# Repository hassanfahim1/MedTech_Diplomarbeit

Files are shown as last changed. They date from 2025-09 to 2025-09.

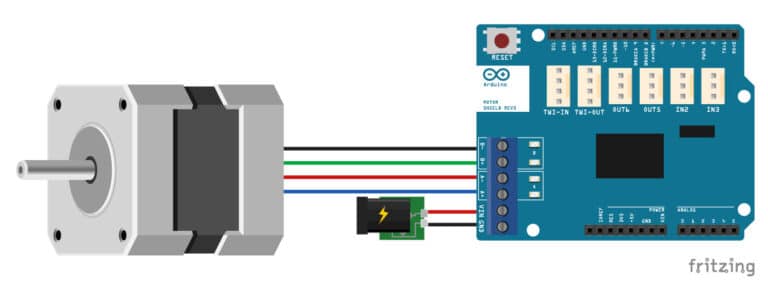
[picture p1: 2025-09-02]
images/Arduino-Motor-Shield-Rev3-with-Stepper-Motor-Wiring-Diagram-Schematic-Pinout-Fritzing-768x290.jpg

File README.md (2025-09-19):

# MedTech_Diplomarbeit | Open Source Spritzenpumpe

Eine präzise, temperaturoptimierte Spritzenpumpe für medizinische und Laboranwendungen.

## 🎯 Features

- **Präzise Volumensteuerung** für 5ml und 10ml Spritzen
- **Temperaturoptimiert** - Motor wird nicht warm durch intelligente Steuerung
- **Einfache Bedienung** mit nur 3 Buttons
- **LCD-Display** mit deutscher Benutzeroberfläche
- **Not-Halt Funktion** für sicheren Betrieb
- **Open Source** - alle Dateien frei verfügbar

## 🔧 Hardware

### Benötigte Komponenten:
- Arduino Leonardo
- Motor Shield Rev3 (L298P)
- NEMA17 Schrittmotor (17HS08-1004S, 3V/1A)
- I2C LCD Display (16x2)
- 3x Taster (Start/Stop, Füllen, Entleeren)
- 5ml oder 10ml Spritzen

### Anschlüsse:
- **Start/Stop Button:** Pin 2
- **Füllen Button:** Pin 7  
- **Entleeren Button:** Pin 5
- **LCD:** I2C (SDA/SCL)
- **Motor Shield:** Standard Pins (3, 8, 9, 11, 12, 13)

## 💾 Code

### Verfügbare Versionen:
- **`spritzenpumpe_5ml.ino`** - Optimiert für 5ml Spritzen
- **`spritzenpumpe_10ml.ino`** - Optimiert für 10ml Spritzen
- **`Spritzenpumpe_10ml_5ml_RotaryEncoder.ino`** - Universalversion mit Rotary Encoder (5ml + 10ml wählbar)

### Installation:
1. Arduino IDE installieren
2. Benötigte Libraries installieren:
   ```
   - Wire.h (Standard)
   - LiquidCrystal_I2C.h
   - Stepper.h (Standard)
   ```
3. Gewünschte Version auf Arduino Leonardo hochladen

## 🚀 Bedienung

1. **Einschalten** - Display zeigt "Ready..."
2. **Füllen** - Button "Füllen" drücken
3. **Entleeren** - Button "Entleeren" drücken  
4. **Start/Stop** - Jederzeit Motor stoppen/starten

### Display-Anzeigen:
- Aktuelles Volumen in ml
- Füll-/Entleervorgang mit Fortschrittsbalken
- Status: "BEREIT" oder "LAUFEND"

## ⚡ Temperatur-Optimierung

**Problem gelöst:** Motor wird nicht mehr warm!

### Technische Lösung:
- Motor nur bei Bewegung bestromt
- Automatische Freigabe nach 2s Inaktivität
- `motorEnable()` / `motorRelease()` Funktionen
- Bis zu 90% weniger Wärmeentwicklung

## 📋 Technische Daten

### 5ml Version:
- Schritte pro ml: 850
- Schritte pro Bewegung: 4250
- Maximales Volumen: 5.00ml

### 10ml Version:  
- Schritte pro ml: 590
- Schritte pro Bewegung: 5900
- Maximales Volumen: 10.00ml

## ⚠️ Wichtige Hinweise

- **L298P hat keine Stromregelung** - Temperatur-Feature ist essentiell
- **Nur für Laboranwendungen** - nicht für medizinische Direktanwendung
- **Kalibrierung** je nach Spritze eventuell anpassen
- **Sicherheit** - immer Not-Halt griffbereit

## 📁 Projektstruktur

```
MedTech_Diplomarbeit/
├── CAD/                        # CAD-Dateien und Zeichnungen
├── Schema/                     # Schaltpläne und Schemas
├── images/                     # Bilder und Dokumentation
├── scr/                        # Source Code
│   ├── spritzenpumpe_5ml.ino                      # Code für 5ml Spritzen
│   ├── spritzenpumpe_10ml.ino                     # Code für 10ml Spritzen
│   └── Spritzenpumpe_10ml_5ml_RotaryEncoder.ino   # Universalversion mit Encoder
└── README.md                   # Diese Datei
```

## 🛠️ Entwicklung

**Hauptverbesserungen in V1.2:**
- ✅ Temperaturproblem gelöst
- ✅ Encoder entfernt für Einfachheit
- ✅ Separate Versionen für 5ml/10ml
- ✅ Verbesserte Benutzeroberfläche

## 📜 Lizenz

Open Source - frei für Bildung und Forschung verwendbar.

## 🔗 Repository

**GitHub:** https://github.com/hassanfahim1/MedTech_Diplomarbeit

---

*Entwickelt als Teil einer Diplomarbeit im Bereich Medizintechnik*

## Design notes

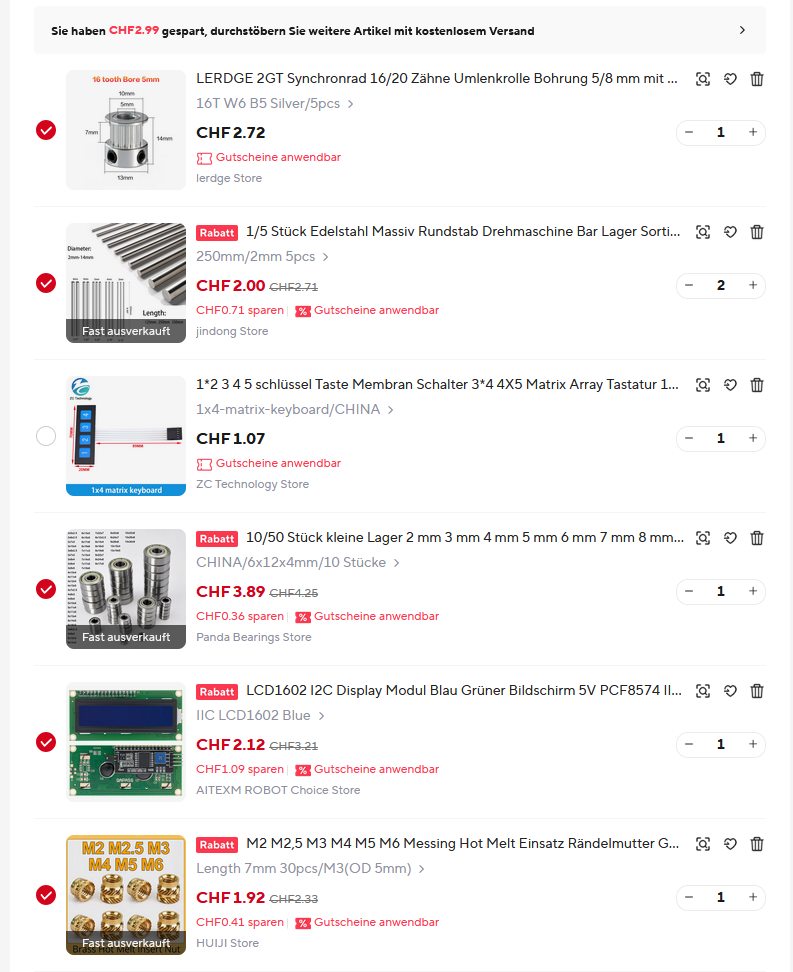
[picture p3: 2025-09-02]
images/Screenshot 2025-08-20 134111.png

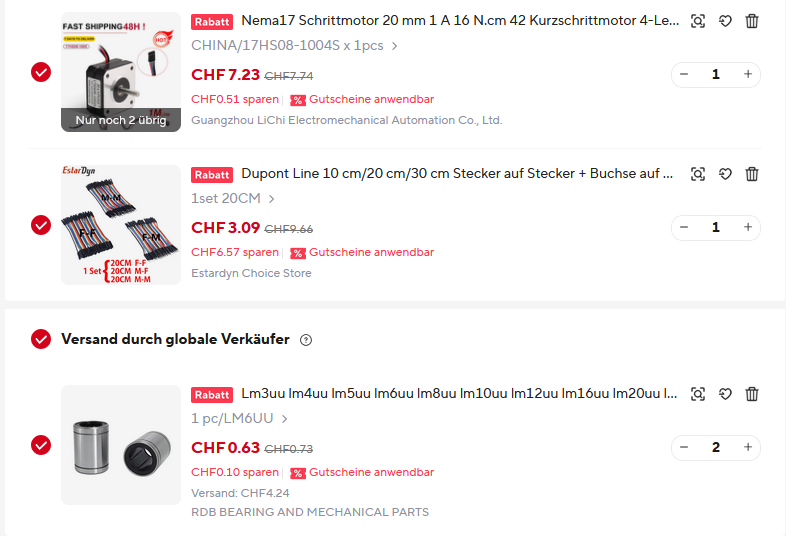
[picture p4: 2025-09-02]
images/Screenshot 2025-08-20 134125.png

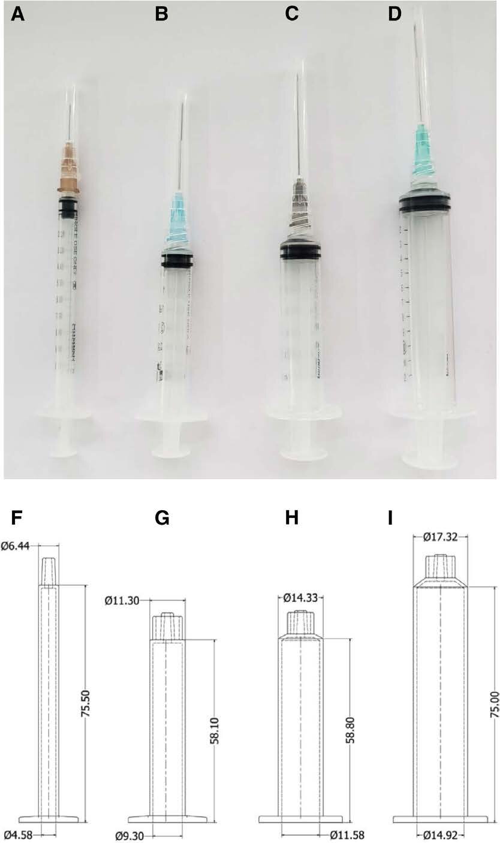
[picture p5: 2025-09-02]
images/Syringe-A-1-mL-B-3-mL-C-5-mL-D-10-mL-and-the-dimension-detail-of-the-barrel.jpg

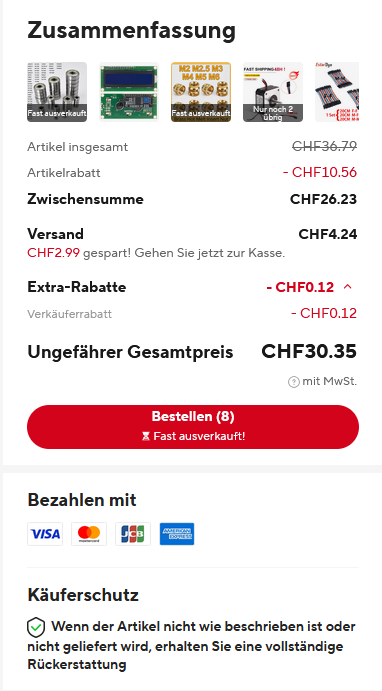
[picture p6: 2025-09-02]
images/Screenshot 2025-08-20 134036.png

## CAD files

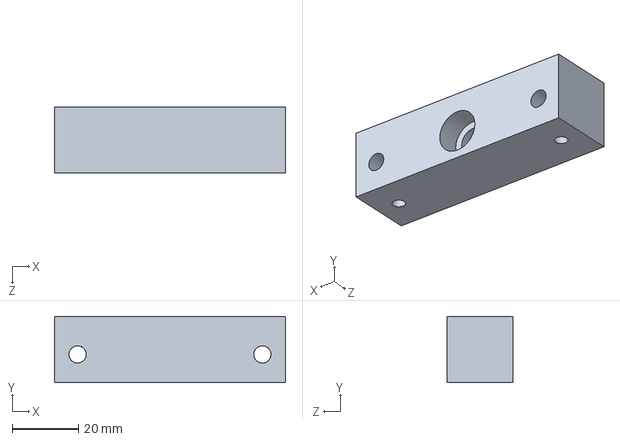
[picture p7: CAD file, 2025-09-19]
CAD/SLDPRT Bauteile/EndTeil ohne Gehäuse.SLDPRT
70.0 x 20.0 x 20.0 mm

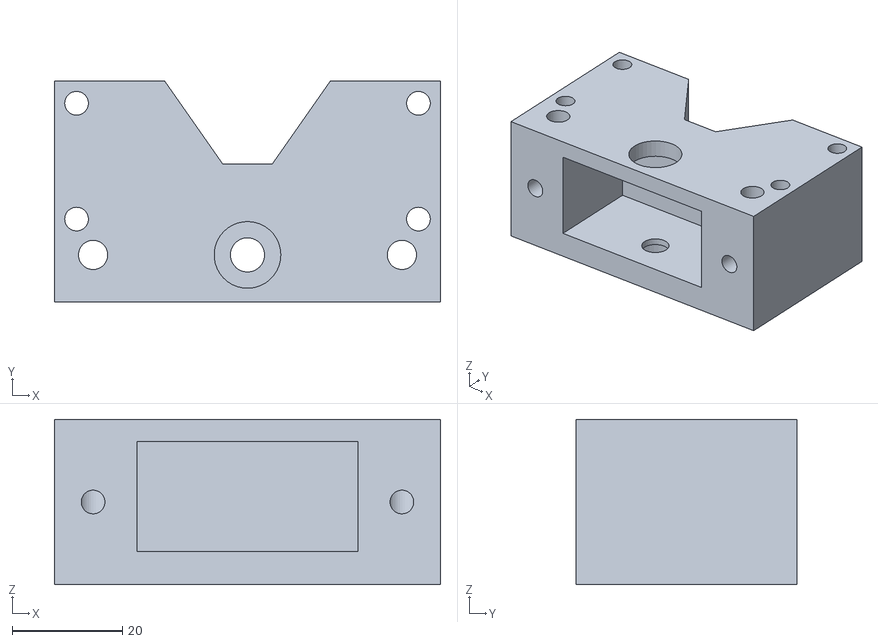
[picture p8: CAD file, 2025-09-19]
CAD/STL Datein/Motorenteil_Spritzenhalter.STL
70.0 x 40.0 x 30.0

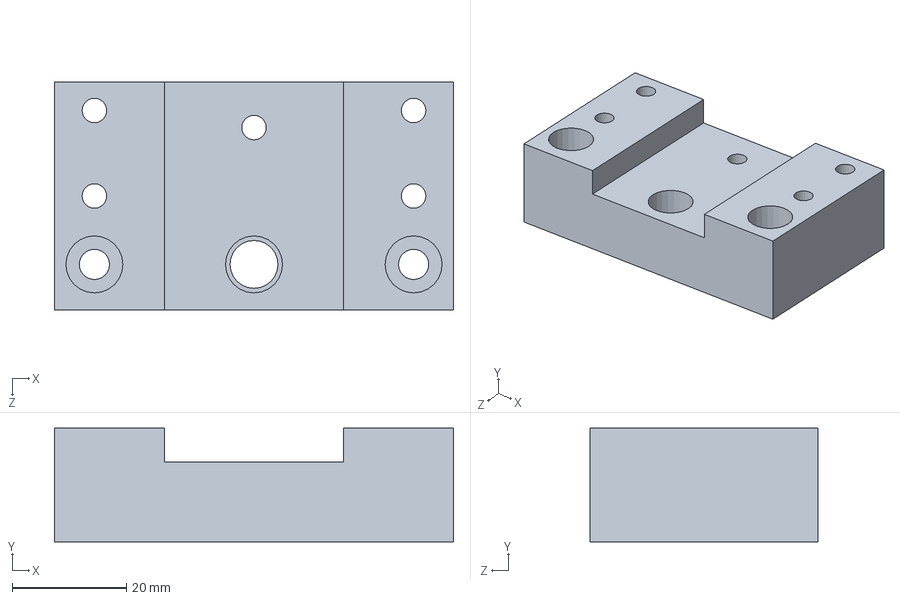
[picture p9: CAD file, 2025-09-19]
CAD/SLDPRT Bauteile/Mittlerer_Teil_Spritzenschieber.SLDPRT
70.0 x 20.0 x 40.0 mm

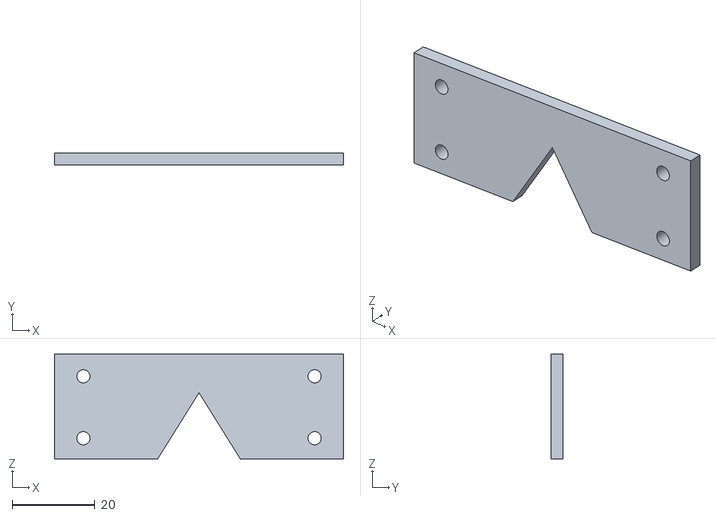
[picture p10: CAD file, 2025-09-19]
CAD/STL Datein/SchiebeTeilSpritzenhalter.STL
70.0 x 3.00 x 25.4

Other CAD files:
CAD/SLDPRT Bauteile/SchiebeTeil.SLDPRT
CAD/STL Datein/Mittlerer_Teil_Spritzenschieber.STL
CAD/SLDPRT Bauteile/Motorenteil_Spritzenhalter.SLDPRT
CAD/STL Datein/EndTeil.STL
CAD/Zeichnungen/EndTeil.SLDDRW
CAD/Zeichnungen/Mittlerer_Teil_Spritzenschieber.SLDDRW
CAD/Zeichnungen/Motorenteil_Spritzenhalter.SLDDRW
CAD/Zeichnungen/SchiebeTeil_Spritzenhalter.SLDDRW

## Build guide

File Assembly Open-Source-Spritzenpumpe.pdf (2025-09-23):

# Assembly Open-Source-Spritzenpumpe

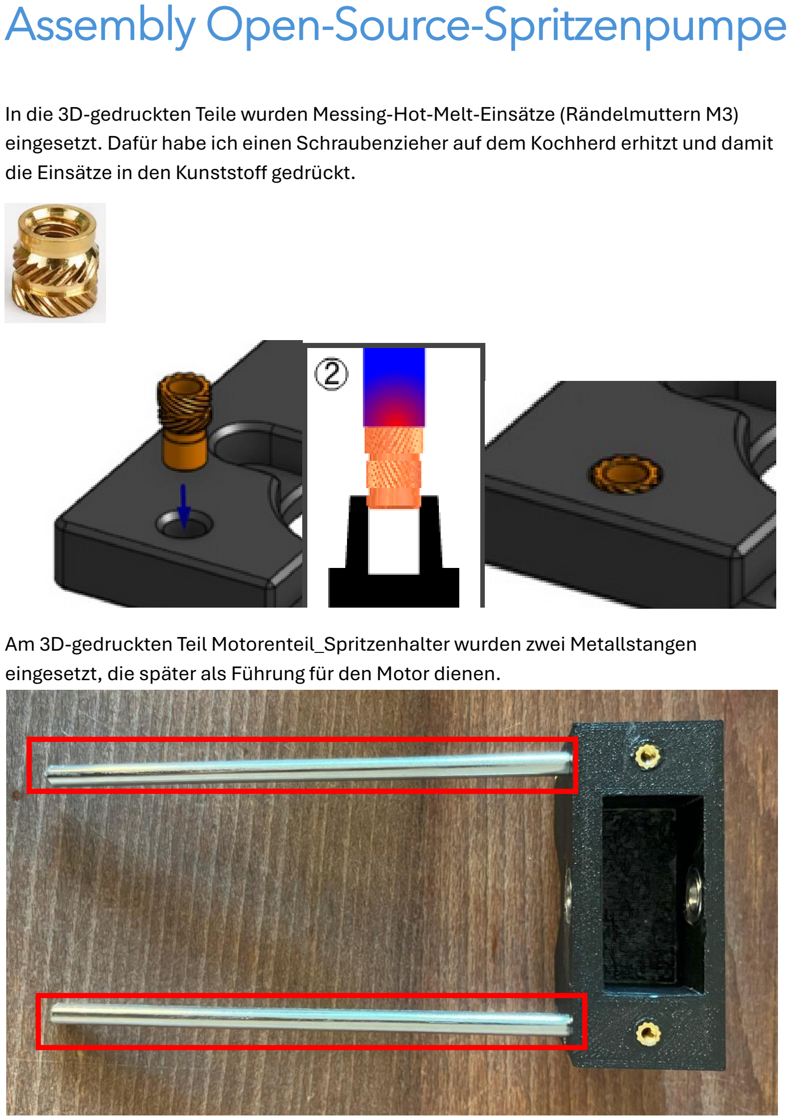
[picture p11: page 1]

In die 3D-gedruckten Teile wurden Messing-Hot-Melt-Einsätze (Rändelmuttern M3) eingesetzt. Dafür habe ich einen Schraubenzieher auf dem Kochherd erhitzt und damit die Einsätze in den Kunststoff gedrückt.

Am 3D-gedruckten Teil Motorenteil_Spritzenhalter wurden zwei Metallstangen eingesetzt, die später als Führung für den Motor dienen.

In der Mitte des Teils Motorenteil_Spritzenhalter wurde die Gewindestange eingesetzt. Darauf wurde ein LERDGE 2GT-Synchronrad mit einem GT2-Zahnriemen (106 mm, Gummi) montiert.

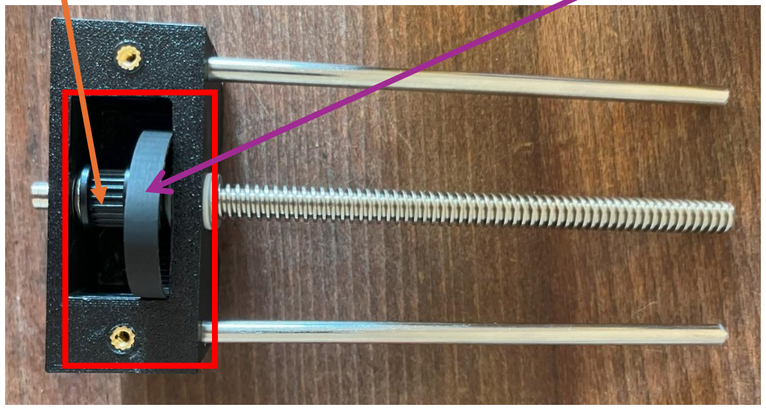
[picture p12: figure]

Im mittleren 3D-Teil der Spritze wurde eine T8-Leitspindel mit Mutter eingesetzt. An den beiden unteren Seiten dieses Teils wurden zwei lineare Kugellager (LM5UU) eingebaut. Dadurch kann sich der Kolben (Mittlerer_Teil_Spritzenschieber) leicht und stabil bewegen.

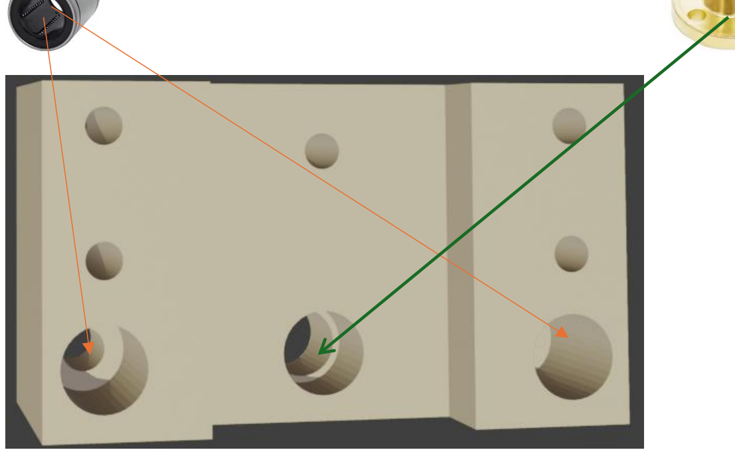
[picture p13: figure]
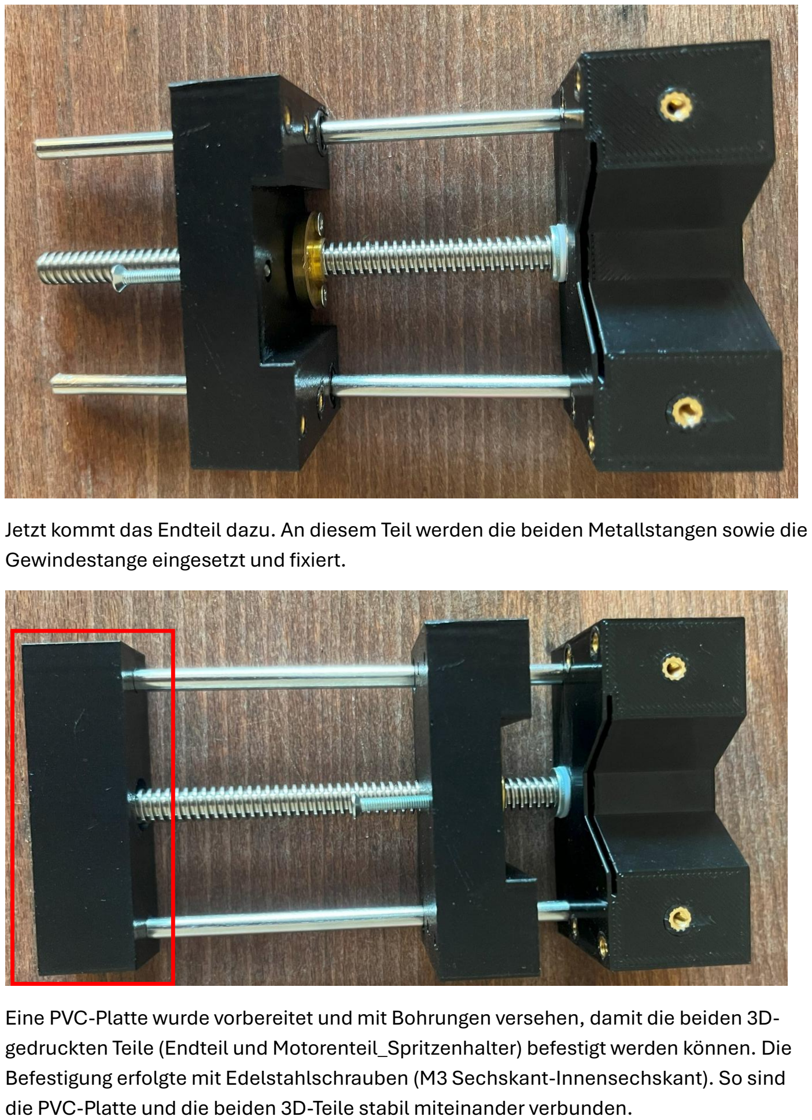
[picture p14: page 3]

Jetzt kommt das Endteil dazu. An diesem Teil werden die beiden Metallstangen sowie die Gewindestange eingesetzt und fixiert.

Eine PVC-Platte wurde vorbereitet und mit Bohrungen versehen, damit die beiden 3D-gedruckten Teile (Endteil und Motorenteil_Spritzenhalter) befestigt werden können. Die Befestigung erfolgte mit Edelstahlschrauben (M3 Sechskant-Innensechskant). So sind die PVC-Platte und die beiden 3D-Teile stabil miteinander verbunden.

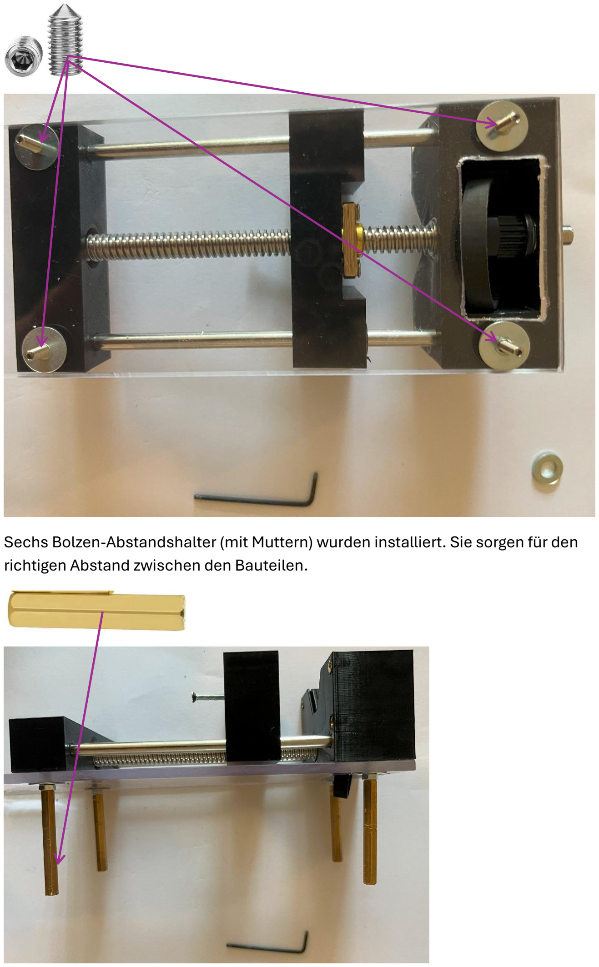
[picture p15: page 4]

Sechs Bolzen-Abstandshalter (mit Muttern) wurden installiert. Sie sorgen für den richtigen Abstand zwischen den Bauteilen.

Eine zweite PVC-Platte wurde vorbereitet, die von unten montiert wird. Damit ist die Spritze vollständig eingefasst. Beide PVC-Platten bilden zusammen ein Gehäuse, in dem sich alle Elektronikteile sowie der Motor befinden.

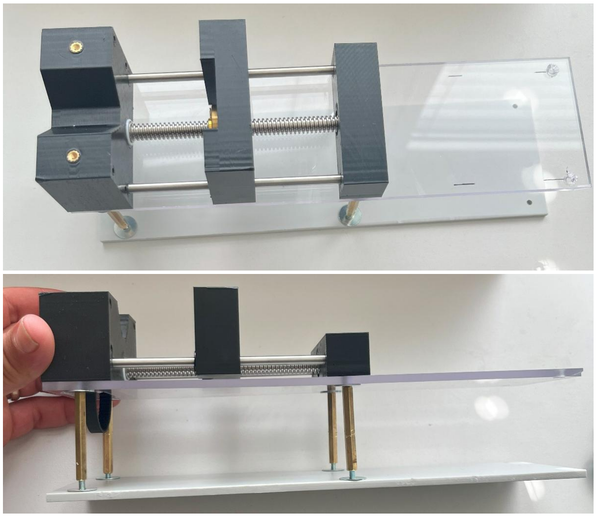
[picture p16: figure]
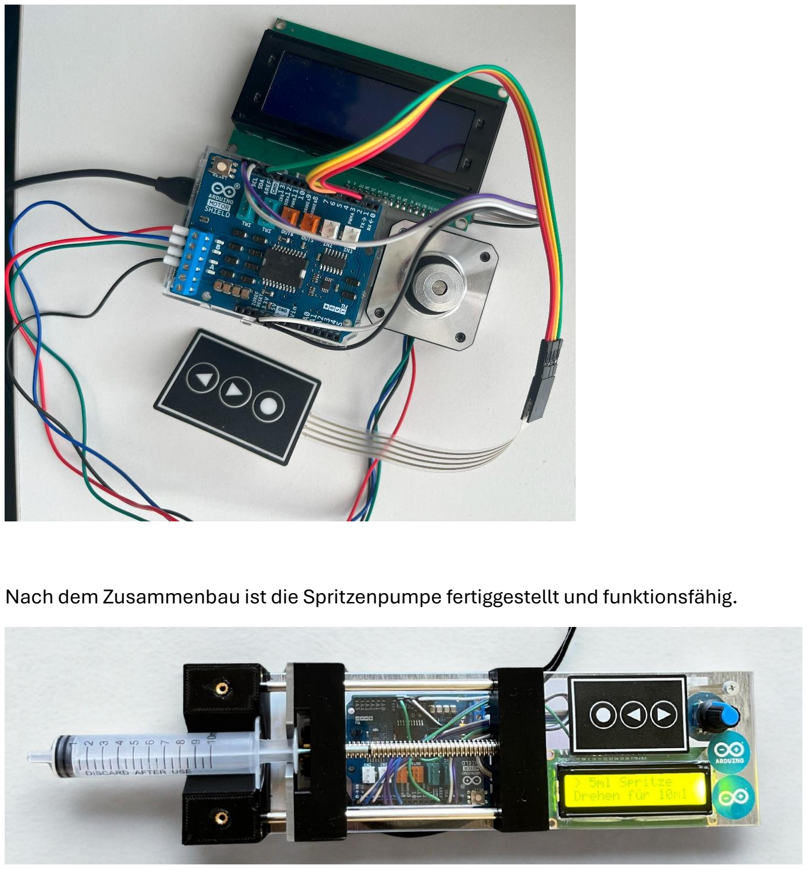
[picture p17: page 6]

Nach dem Zusammenbau ist die Spritzenpumpe fertiggestellt und funktionsfähig.

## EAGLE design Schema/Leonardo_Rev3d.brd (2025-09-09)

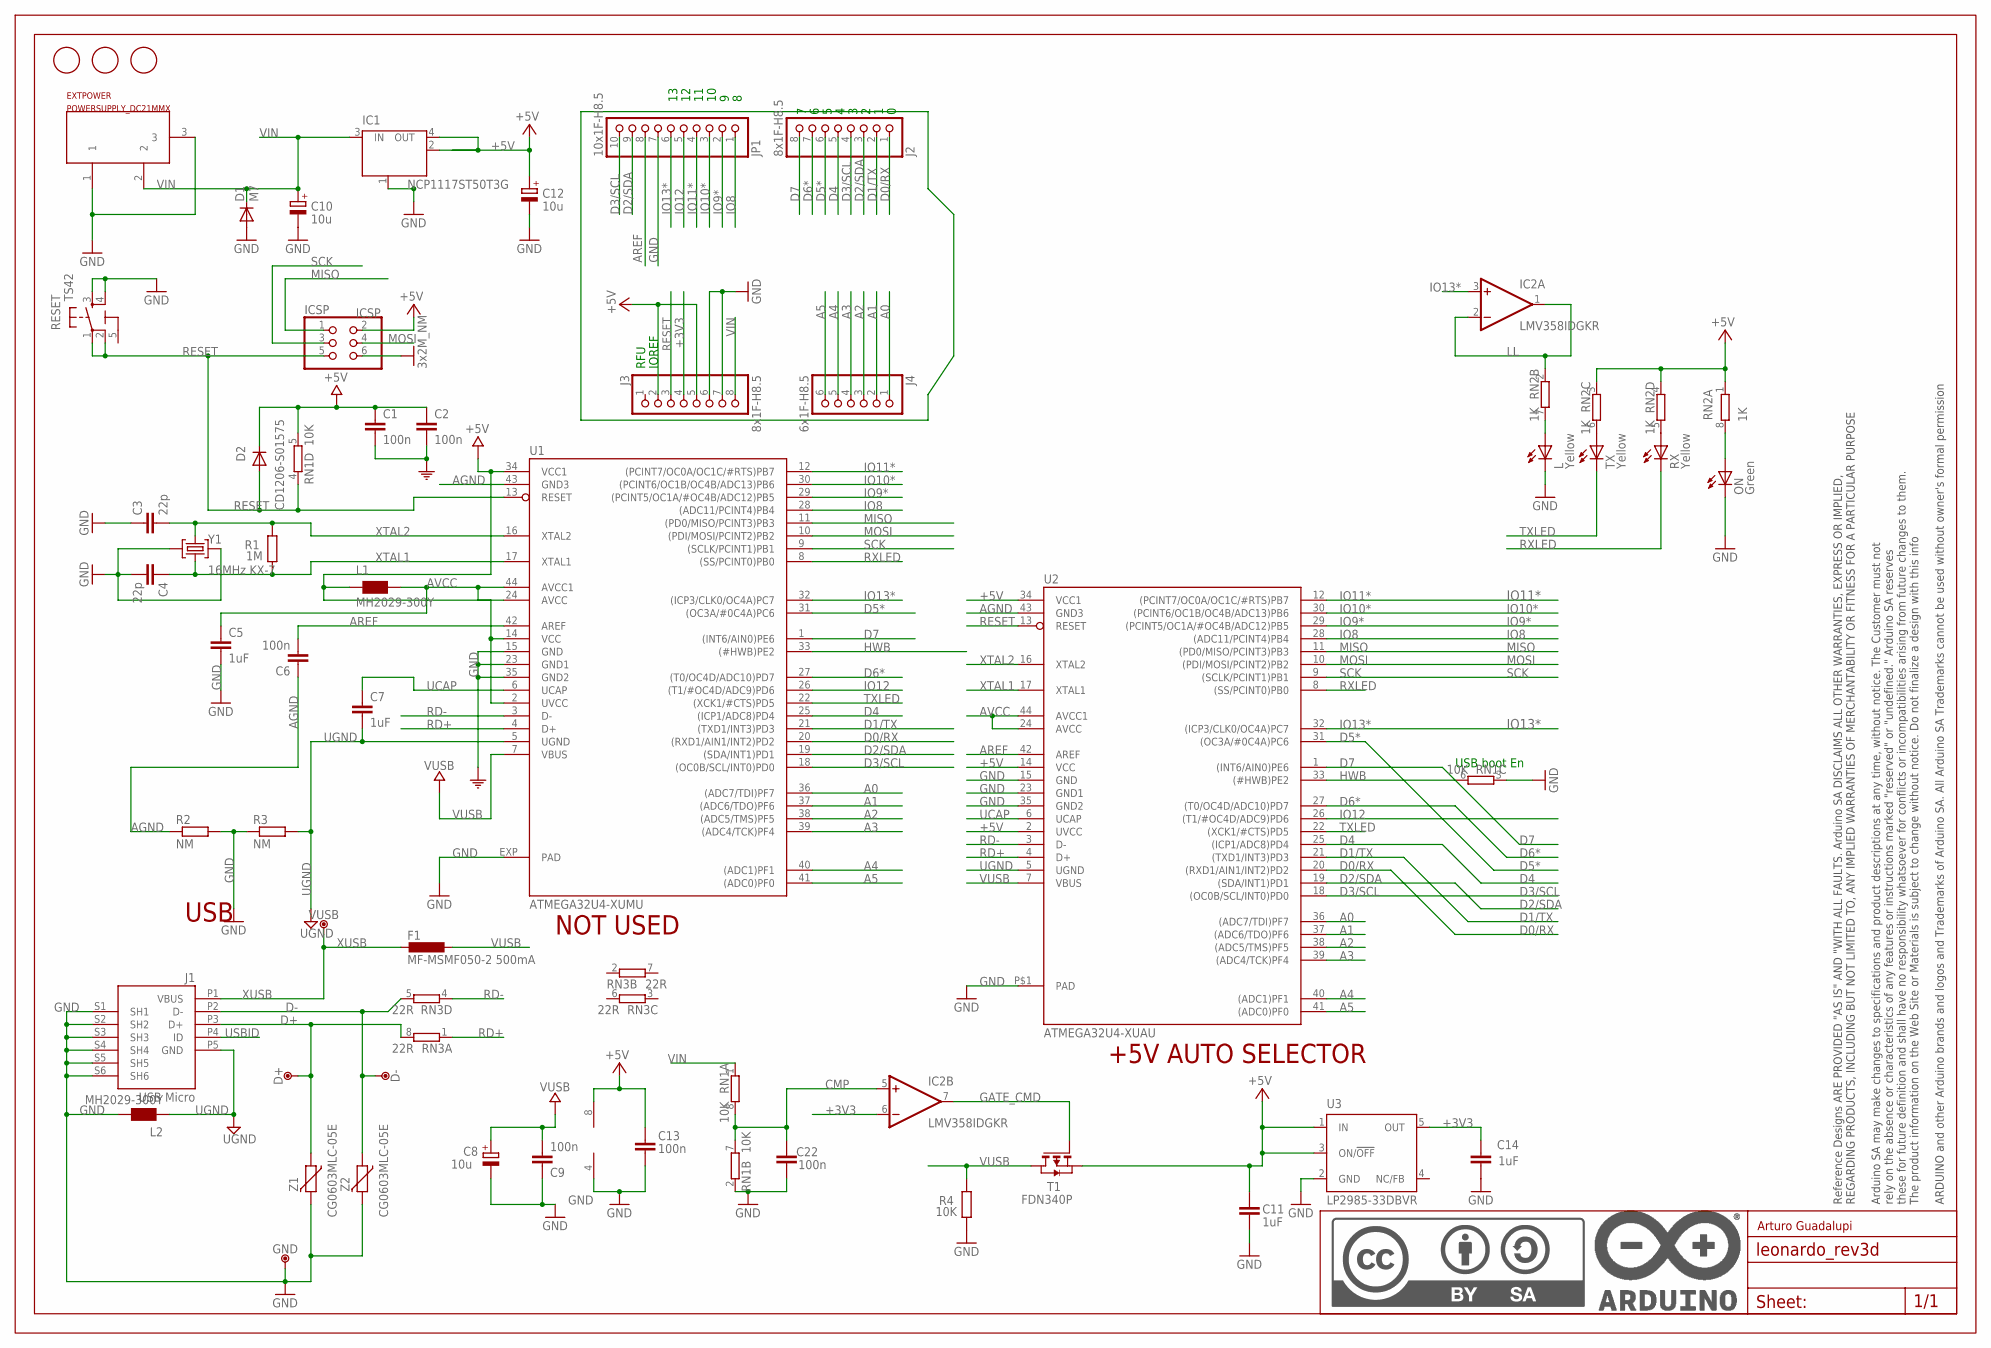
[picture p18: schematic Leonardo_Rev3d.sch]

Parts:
C1, C2, C6, C9, C13, C22: 100n; C0603-ROUND
C3, C4: 22p; C0603-ROUND
C5, C7, C11, C14: 1uF; C0603-ROUND
C8, C10, C12: 10u; SMC_B
D1: M7; SMB
D2: CD1206-S01575; MINIMELF
D+: DNP; TP-1.00MM
D-: DNP; TP-1.00MM
EXTPOWER: POWERSUPPLY_DC21MMX; POWERSUPPLY_DC-21MM
F1: MF-MSMF050-2 500mA; L1812
FID1, FID2, FID3: DNP; FD-1-1.5
FRAME1: DNP; FRAME
GND: DNP; TP-1.00MM
IC1: NCP1117ST50T3G; SOT223
IC2: LMV358IDGKR; MSOP08
ICSP: ICSP; 2X03
J1: USB Micro; CON2_USB_MICRO_B_AT
J2, J3: 8x1F-H8.5; 1X08
J4: 6x1F-H8.5; 1X06
JP1: 10x1F-H8.5; 1X10
L: Yellow; CHIPLED_0805
L1, L2: MH2029-300Y; 0805
ON: Green; CHIPLED_0805
R1: 1M; R0603-ROUND
R2, R3: NM; R0402
R4: 10K; R0603-ROUND
RESET: TS42
RN1: 10K; CAY16
RN2: 1K; CAY16
RN3: 22R; CAY16
RX: Yellow; CHIPLED_0805
T1: FDN340P; SOT-23
TX: Yellow; CHIPLED_0805
U1: ATMEGA32U4-XUMU; QFN44ML7X7
U2: ATMEGA32U4-XUAU; TQFP44-PAD
U3: LP2985-33DBVR; SOT23-DBV
VUSB: DNP; TP-1.00MM
Y1: 16MHz KX-7; CRYSTAL-3.2-2.5
Z1, Z2: CG0603MLC-05E; CT/CN0603

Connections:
5-GND: RESET.5 (5-GND)
+3V3: C14.2, IC2.6 (-IN), J3.4, U3.5 (OUT)
+5V: C1.1, C2.1, C11.2, C12.+, C13.1, D2.C, IC1.2 (OUT), IC1.4 (OUT), IC2.8 (V+), ICSP.2, J3.2, J3.5, L1.1, RN1.5 (2), RN2.1, RN2.3 (1), RN2.4 (1), T1.2 (S), U1.2 (UVCC), U1.14 (VCC), U1.34 (VCC1), U2.2 (UVCC), U2.14 (VCC), U2.34 (VCC1), U3.1 (IN), U3.3 (ON/!OFF)
A0: J4.1, U1.36 ((ADC7/TDI)PF7), U2.36 ((ADC7/TDI)PF7)
A1: J4.2, U1.37 ((ADC6/TDO)PF6), U2.37 ((ADC6/TDO)PF6)
A2: J4.3, U1.38 ((ADC5/TMS)PF5), U2.38 ((ADC5/TMS)PF5)
A3: J4.4, U1.39 ((ADC4/TCK)PF4), U2.39 ((ADC4/TCK)PF4)
A4: J4.5, U1.40 ((ADC1)PF1), U2.40 ((ADC1)PF1)
A5: J4.6, U1.41 ((ADC0)PF0), U2.41 ((ADC0)PF0)
AGND: C6.1, R2.1, U1.43 (GND3), U2.43 (GND3)
AREF: C6.2, JP1.8, U1.42 (AREF), U2.42 (AREF)
AVCC: C5.1, L1.2, U1.24 (AVCC), U1.44 (AVCC1), U2.24 (AVCC), U2.44 (AVCC1)
CMP: C22.2, IC2.5 (+IN), RN1.7 (2), RN1.8 (2)
D0/RX: J2.1, U1.20 ((RXD1/AIN1/INT2)PD2), U2.20 ((RXD1/AIN1/INT2)PD2)
D1/TX: J2.2, U1.21 ((TXD1/INT3)PD3), U2.21 ((TXD1/INT3)PD3)
D2/SDA: J2.3, JP1.9, U1.19 ((SDA/INT1)PD1), U2.19 ((SDA/INT1)PD1)
D3/SCL: J2.4, JP1.10, U1.18 ((OC0B/SCL/INT0)PD0), U2.18 ((OC0B/SCL/INT0)PD0)
D4: J2.5, U1.25 ((ICP1/ADC8)PD4), U2.25 ((ICP1/ADC8)PD4)
D5*: J2.6, U1.31 ((OC3A/#0C4A)PC6), U2.31 ((OC3A/#0C4A)PC6)
D6*: J2.7, U1.27 ((T0/OC4D/ADC10)PD7), U2.27 ((T0/OC4D/ADC10)PD7)
D7: J2.8, U1.1 ((INT6/AIN0)PE6), U2.1 ((INT6/AIN0)PE6)
D+: D+.X, J1.P3 (D+), RN3.8 (2), Z1.1
D-: D-.X, J1.P2 (D-), RN3.5 (2), Z2.1
GATE_CMD: IC2.7 (OUT), T1.3 (G)
GND: C1.2, C2.2, C3.1, C4.2, C5.2, C8.-, C9.1, C10.-, C11.1, C12.-, C13.2, C14.1, C22.1, D1.A, EXTPOWER.1, EXTPOWER.3, GND.X, IC1.1 (GND/ADJ), IC2.4 (V-), ICSP.6, J1.S1 (SH1), J1.S2 (SH2), J1.S3 (SH3), J1.S4 (SH4), J1.S5 (SH5), J1.S6 (SH6), J3.6, J3.7, JP1.7, L.C, L2.2, ON.C, R2.2, R3.1, R4.1, RESET.3, RESET.4, RN1.2 (1), RN1.3 (1), U1.15 (GND), U1.23 (GND1), U1.35 (GND2), U1.EXP (PAD), U2.15 (GND), U2.23 (GND1), U2.35 (GND2), U2.P$1 (PAD), U3.2 (GND), Y1.2 (GND), Y1.4 (GND), Z1.2, Z2.2
HWB: RN1.6 (2), U1.33 ((#HWB)PE2), U2.33 ((#HWB)PE2)
IO8: JP1.1, U1.28 ((ADC11/PCINT4)PB4), U2.28 ((ADC11/PCINT4)PB4)
IO9*: JP1.2, U1.29 ((PCINT5/OC1A/#OC4B/ADC12)PB5), U2.29 ((PCINT5/OC1A/#OC4B/ADC12)PB5)
IO10*: JP1.3, U1.30 ((PCINT6/OC1B/OC4B/ADC13)PB6), U2.30 ((PCINT6/OC1B/OC4B/ADC13)PB6)
IO11*: JP1.4, U1.12 ((PCINT7/OC0A/OC1C/#RTS)PB7), U2.12 ((PCINT7/OC0A/OC1C/#RTS)PB7)
IO12: JP1.5, U1.26 ((T1/#OC4D/ADC9)PD6), U2.26 ((T1/#OC4D/ADC9)PD6)
IO13*: IC2.3 (+IN), JP1.6, U1.32 ((ICP3/CLK0/OC4A)PC7), U2.32 ((ICP3/CLK0/OC4A)PC7)
LL: IC2.1 (OUT), IC2.2 (-IN), RN2.2 (1)
MISO: ICSP.1, U1.11 ((PD0/MISO/PCINT3)PB3), U2.11 ((PD0/MISO/PCINT3)PB3)
MOSI: ICSP.4, U1.10 ((PDI/MOSI/PCINT2)PB2), U2.10 ((PDI/MOSI/PCINT2)PB2)
unnamed: L.A, RN2.7 (2)
unnamed: ON.A, RN2.8 (2)
unnamed: RN2.6 (2), TX.A
unnamed: RN2.5 (2), RX.A
RD+: RN3.1, U1.4 (D+), U2.4 (D+)
RD-: RN3.4 (1), U1.3 (D-), U2.3 (D-)
RESET: D2.A, ICSP.5, J3.3, RESET.1, RESET.2, RN1.4 (1), U1.13 (RESET), U2.13 (RESET)
RXLED: RX.C, U1.8 ((SS/PCINT0)PB0), U2.8 ((SS/PCINT0)PB0)
SCK: ICSP.3, U1.9 ((SCLK/PCINT1)PB1), U2.9 ((SCLK/PCINT1)PB1)
TXLED: TX.C, U1.22 ((XCK1/#CTS)PD5), U2.22 ((XCK1/#CTS)PD5)
UCAP: C7.1, U1.6 (UCAP), U2.6 (UCAP)
UGND: C7.2, J1.P5 (GND), L2.1, R3.2, U1.5 (UGND), U2.5 (UGND)
USBID: J1.P4 (ID)
VIN: C10.+, D1.C, EXTPOWER.2, IC1.3 (IN), J3.8, RN1.1
VUSB: C8.+, C9.2, F1.1, R4.2, T1.1 (D), U1.7 (VBUS), U2.7 (VBUS)
XTAL1: C4.1, R1.1, U1.17 (XTAL1), U2.17 (XTAL1), Y1.1 (C1)
XTAL2: C3.2, R1.2, U1.16 (XTAL2), U2.16 (XTAL2), Y1.3 (C2)
XUSB: F1.2, J1.P1 (VBUS), VUSB.X

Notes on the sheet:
USB boot En
USB
+5V AUTO SELECTOR
NOT USED
IOREF
RFU
Arturo Guadalupi

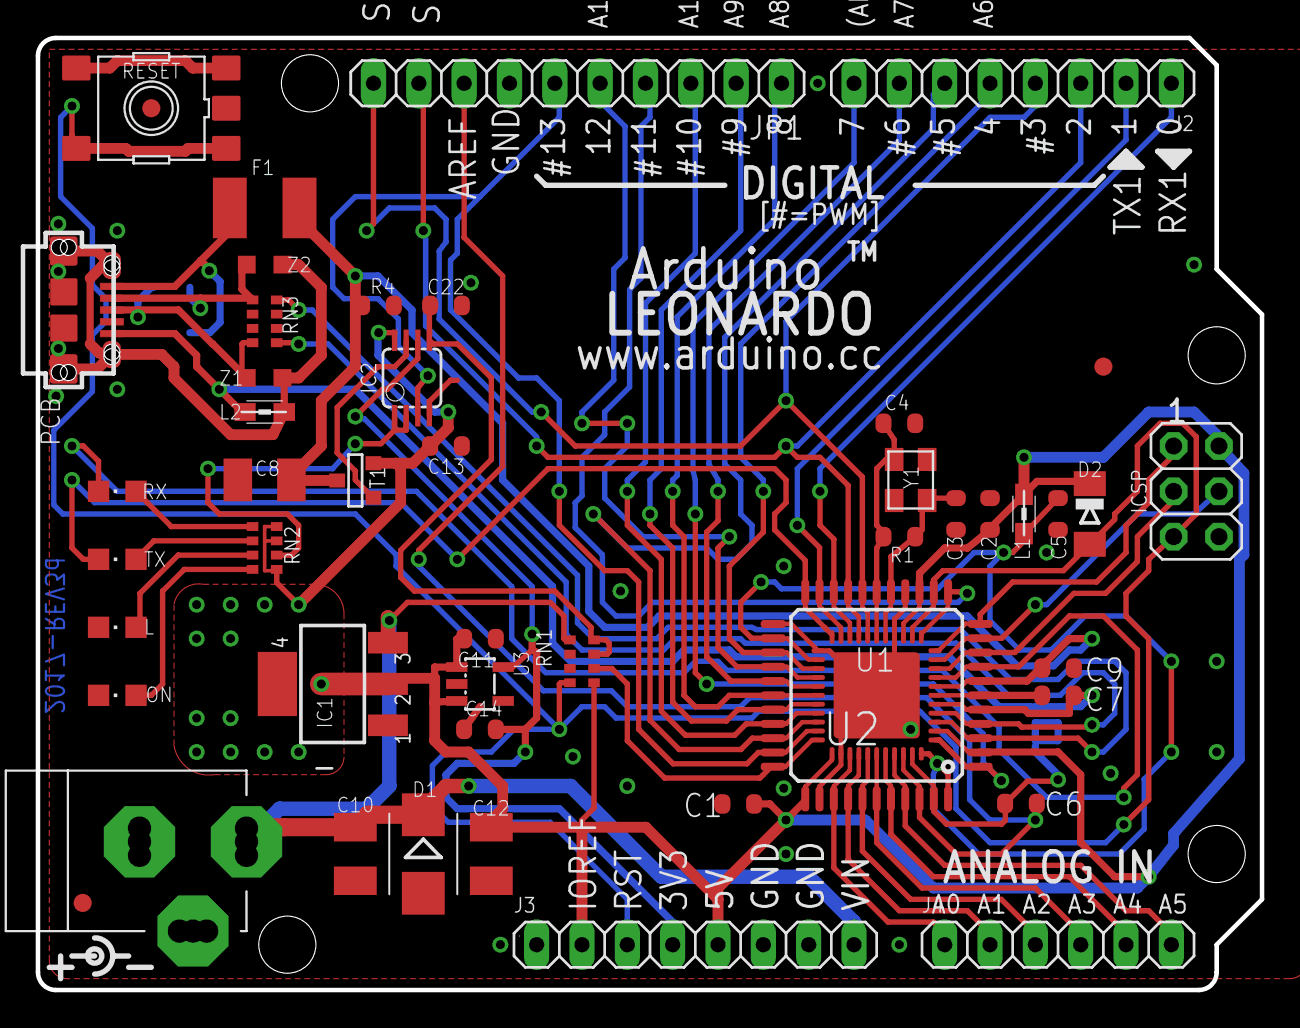
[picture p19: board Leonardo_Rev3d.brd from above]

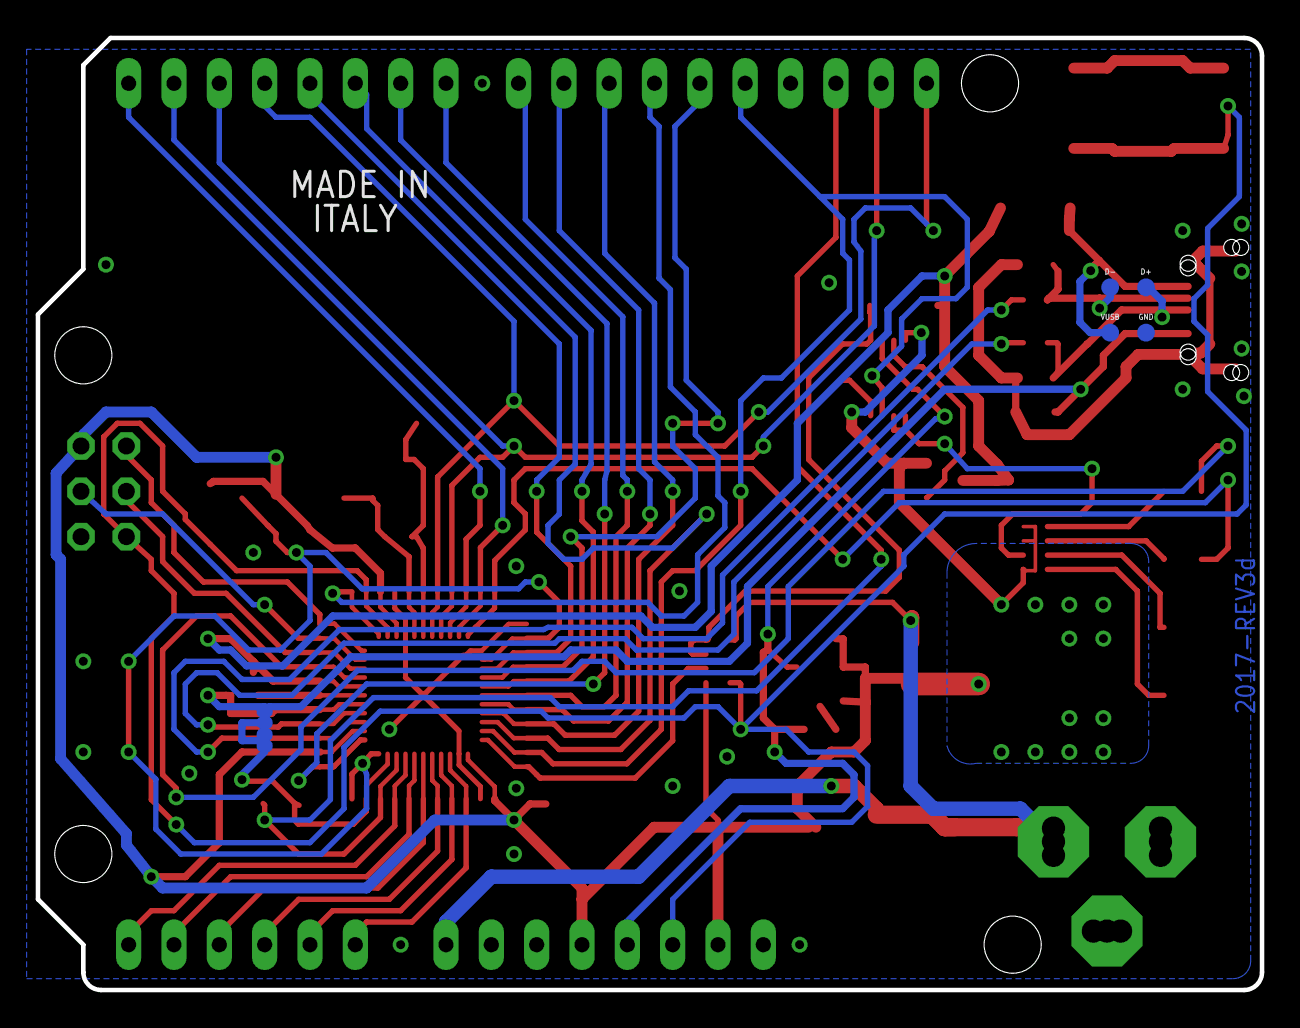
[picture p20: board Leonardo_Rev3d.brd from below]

Board: 2 copper layers, 68.6 x 53.3 mm, 56 parts (2 on the bottom side), 51 nets.

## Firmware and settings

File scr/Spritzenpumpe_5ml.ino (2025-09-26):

/*
 * Open Source Spritzenpumpe - 5ml Version (Thermik-Optimierung)
 * - Nur für 5ml Spritzen optimiert
 * - Ohne Encoder - nur 3 Buttons
 * - motorEnable() / motorRelease() für weniger Wärme im Stillstand
 * - Idle-Timer: Nach 2 s Inaktivität werden die Phasen freigegeben
 *
 * Hardware:
 * Arduino Leonardo + Motor Shield Rev3 (L298P) + I2C LCD + 3 Buttons
 * NEMA17 17HS08-1004S (3V/1A)
 */

#include <Wire.h>
#include <LiquidCrystal_I2C.h>
#include <Stepper.h>

// ----------------- Hier sind alle Motor Shield Rev3 Pins (Anschlüsse) -----------------
#define pwmA   3
#define pwmB  11
#define brakeA 9
#define brakeB 8
#define dirA  12
#define dirB  13

// ----------------- Die drei Taster wo ich angeschlossen habe -----------------
#define BTN_START_STOP 2    // Stop/Start Button
#define BTN_FILL       7    // Füllen Button
#define BTN_EMPTY      5    // Entleeren Button

// ----------------- Motor Einstellung -----------------
const int stepsPerRevolution = 200;
Stepper myStepper = Stepper(stepsPerRevolution, dirA, dirB);

// ----------------- LCD Display -----------------
LiquidCrystal_I2C lcd(0x27, 16, 2);

// ----------------- Deutsche Umlaute selbst gemacht weil LCD sie nicht kann -----------------
byte umlaut_ue[8] = {0x0A,0x00,0x11,0x11,0x11,0x13,0x0D,0x00}; // ü
byte umlaut_ae[8] = {0x0A,0x00,0x0E,0x01,0x0F,0x11,0x0F,0x00}; // ä
byte umlaut_oe[8] = {0x0A,0x00,0x0E,0x11,0x11,0x11,0x0E,0x00}; // ö
byte umlaut_UE[8] = {0x0A,0x00,0x11,0x11,0x11,0x11,0x0E,0x00}; // Ü
byte umlaut_AE[8] = {0x0A,0x00,0x0E,0x11,0x1F,0x11,0x11,0x00}; // Ä
byte umlaut_OE[8] = {0x0A,0x00,0x0E,0x11,0x11,0x11,0x0E,0x00}; // Ö

#define CHAR_UE_KLEIN 0
#define CHAR_AE_KLEIN 1
#define CHAR_OE_KLEIN 2
#define CHAR_UE_GROSS 3
#define CHAR_AE_GROSS 4
#define CHAR_OE_GROSS 5

// ----------------- Einstellungen für 5ml Spritze (getestet und funktioniert gut) -----------------
const int stepSize = 4250;           // soviele Schritte braucht für ganze Spritze
const float stepsPerML = 850.0;      // Schritte für einen ml
const int minSteps = -4250;          // minimum Position wenn Spritze voll ist
const float targetVolume = 5.0;      // maximum Volumen

// ----------------- verschiedene Zustände vom System -----------------
bool motorRunning = false;
bool motorStopped = false;
bool lastStopStartState = HIGH;
bool lastFillState = HIGH;
bool lastEmptyState = HIGH;

bool currentStopStartState = HIGH;
bool currentFillState = HIGH;
bool currentEmptyState = HIGH;

int motorSpeed = 120; // Geschwindigkeit in rpm, nicht zu schnell sonst verliert Schritte

// ----------------- Button-Entprellung für stabile Funktion -----------------
// Mechanische Buttons "prellen" beim Drücken mehrmals schnell
// Ohne diese Wartezeit würde ein Druck als mehrere Drücke erkannt werden
// Das führt zu ungewollten mehrfach-Ausführungen
unsigned long lastDebounceTime = 0;
unsigned long debounceDelay = 50;

int totalSteps = 0;

// ----------------- Zeit messen für Operationen -----------------
unsigned long operationStartTime = 0;
unsigned long operationDuration  = 0;
bool operationInProgress = false;

// ----------------- Motor wird heiß Fix -----------------
static unsigned long lastMoveMs = 0;
const unsigned long IDLE_RELEASE_MS = 2000; // nach 2 Sekunden Motor freigeben

// Optional: bisschen Strom lassen statt ganz freigeben
// 0..255 Wert; 0 = komplett freigeben, ca 60-80 = bisschen halten
#define HALTESTROM_DUTY 0   // auf >0 setzen wenn Motor bisschen halten soll

// ----------------- Hilfs Funktionen -----------------
void noteActivity() { lastMoveMs = millis(); }

// Motor freigeben damit er nicht überhitzt
// Wenn Motor steht soll kein Strom fließen, sonst wird er zu heiß
void motorRelease() {
  if (HALTESTROM_DUTY == 0) {
    // komplett freigeben
    digitalWrite(pwmA, LOW);
    digitalWrite(pwmB, LOW);
    digitalWrite(brakeA, HIGH); // Bremse an
    digitalWrite(brakeB, HIGH);
  } else {
    // bisschen Strom lassen falls nötig
    digitalWrite(brakeA, LOW);
    digitalWrite(brakeB, LOW);
    analogWrite(pwmA, HALTESTROM_DUTY);
    analogWrite(pwmB, HALTESTROM_DUTY);
  }
}

// Motor anschalten bevor er sich bewegen soll
void motorEnable() {
  digitalWrite(brakeA, LOW);
  digitalWrite(brakeB, LOW);
  // volle Power geben
  if (HALTESTROM_DUTY == 0) {
    digitalWrite(pwmA, HIGH);
    digitalWrite(pwmB, HIGH);
  } else {
    analogWrite(pwmA, 255);
    analogWrite(pwmB, 255);
  }
}

// ----------------- Setup läuft einmal beim Start -----------------
void setup() {
  pinMode(pwmA, OUTPUT);
  pinMode(pwmB, OUTPUT);
  pinMode(brakeA, OUTPUT);
  pinMode(brakeB, OUTPUT);

  // am Anfang Motor freigeben
  motorRelease();

  pinMode(BTN_START_STOP, INPUT_PULLUP);
  pinMode(BTN_FILL,       INPUT_PULLUP);
  pinMode(BTN_EMPTY,      INPUT_PULLUP);

  myStepper.setSpeed(motorSpeed);

  Wire.begin();
  lcd.init();
  lcd.backlight();

  lcd.createChar(CHAR_UE_KLEIN, umlaut_ue);
  lcd.createChar(CHAR_AE_KLEIN, umlaut_ae);
  lcd.createChar(CHAR_OE_KLEIN, umlaut_oe);
  lcd.createChar(CHAR_UE_GROSS, umlaut_UE);
  lcd.createChar(CHAR_AE_GROSS, umlaut_AE);
  lcd.createChar(CHAR_OE_GROSS, umlaut_OE);

  lcd.setCursor(0, 0);
  lcd.print("5ml Spritzenpumpe");
  lcd.setCursor(0, 1);
  lcd.print("V1.2 HFMTS");
  delay(2000);

  updatePumpDisplay();
  noteActivity();
}

// ----------------- Main Loop läuft immer und immer -----------------
void loop() {
  handlePumpOperation();

  // wenn nichts passiert nach 2 Sekunden Motor freigeben
  if (!motorRunning && !operationInProgress) {
    if (millis() - lastMoveMs > IDLE_RELEASE_MS) {
      motorRelease();
    }
  }

  delay(10);
}

// ----------------- Hier wird alles mit den Buttons gemacht -----------------
void handlePumpOperation() {
  currentStopStartState = digitalRead(BTN_START_STOP);
  currentFillState      = digitalRead(BTN_FILL);
  currentEmptyState     = digitalRead(BTN_EMPTY);

  if (currentStopStartState != lastStopStartState) {
    lastDebounceTime = millis();
  }

  if ((millis() - lastDebounceTime) > debounceDelay) {
    if (currentStopStartState == LOW && lastStopStartState == HIGH) {
      if (motorRunning || operationInProgress) {
        motorRunning = false;
        motorStopped = true;

        if (operationInProgress) {
          operationDuration = (millis() - operationStartTime) / 1000;
          operationInProgress = false;
        }
        updatePumpDisplay();
        motorRelease(); // sofort freigeben damit Motor nicht überhitzt
      } else {
        motorRunning = true;
        motorStopped = false;
        operationStartTime = millis();
        operationInProgress = true;
        motorEnable(); // Motor bereit machen
      }
    }
  }
  lastStopStartState = currentStopStartState;

  if (currentFillState == LOW && lastFillState == HIGH) {
    if (totalSteps <= minSteps) {
      lcd.clear();
      lcd.setCursor(0, 0);
      lcd.print("MAX erreicht");
      lcd.setCursor(0, 1);
      lcd.print("5ml - voll!");
      delay(1200);
      updatePumpDisplay();
    } else {
      performFillOperation();
    }
  }
  lastFillState = currentFillState;

  if (currentEmptyState == LOW && lastEmptyState == HIGH) {
    if (totalSteps >= 0) {
      lcd.clear();
      lcd.setCursor(0, 0);
      lcd.print("NULLSTELLE");
      lcd.setCursor(0, 1);
      lcd.print("0.00ml - leer!");
      delay(1200);
      updatePumpDisplay();
    } else {
      performEmptyOperation();
    }
  }
  lastEmptyState = currentEmptyState;

  if (motorRunning) {
    motorEnable();
    myStepper.step(1);
    noteActivity();
    static unsigned long lastDisplayUpdate = 0;
    if (millis() - lastDisplayUpdate > 500) {
      updatePumpDisplay();
      lastDisplayUpdate = millis();
    }
  }
}

void performFillOperation() {
  motorRunning = false;
  motorStopped = false;
  operationInProgress = true;
  operationStartTime = millis();

  motorEnable();

  for (int i = 0; i < stepSize; i++) {
    // schauen ob schon voll ist
    if (totalSteps - i <= minSteps) {
      motorStopped = true;
      operationDuration = (millis() - operationStartTime) / 1000;
      operationInProgress = false;
      totalSteps -= i;

      lcd.clear();
      lcd.setCursor(0, 0);
      lcd.print("MAX erreicht");
      lcd.setCursor(0, 1);
      lcd.print("5ml - voll!");
      delay(1200);
      break;
    }

    // Stop Button gedrückt?
    if (digitalRead(BTN_START_STOP) == LOW) {
      motorStopped = true;
      operationDuration = (millis() - operationStartTime) / 1000;
      operationInProgress = false;
      totalSteps -= i;
      motorRelease();
      delay(150);
      break;
    }

    // einen Schritt rückwärts (füllen)
    myStepper.step(-1);
    noteActivity();

    if (i % 100 == 0) {
      float currentVol = abs((float)(totalSteps - i) / stepsPerML);
      unsigned long currentTime = (millis() - operationStartTime) / 1000;

      lcd.clear();
      lcd.setCursor(0, 0);
      lcd.print("F");
      lcd.write(CHAR_UE_GROSS);
      lcd.print("llen:");
      lcd.print(currentVol, 2);
      lcd.print("ml");

      lcd.setCursor(0, 1);
      lcd.print(currentTime);
      lcd.print("s ");

      int currentHashes = (int)((currentVol / targetVolume) * 13.0);
      if (currentHashes > 13) currentHashes = 13;
      for (int h = 0; h < currentHashes; h++) lcd.print("#");
    }
  }

  if (!motorStopped) {
    totalSteps -= stepSize;
    operationDuration = (millis() - operationStartTime) / 1000;
    operationInProgress = false;
  }

  updatePumpDisplay();
  motorRelease();   // Motor freigeben nach Operation
  noteActivity();   // Timer zurücksetzen
  delay(80);
}

void performEmptyOperation() {
  motorRunning = false;
  motorStopped = false;
  operationInProgress = true;
  operationStartTime = millis();

  motorEnable();

  for (int i = 0; i < stepSize; i++) {
    // schauen ob schon leer ist
    if (totalSteps + i >= 0) {
      motorStopped = true;
      operationDuration = (millis() - operationStartTime) / 1000;
      operationInProgress = false;
      totalSteps += i;

      lcd.clear();
      lcd.setCursor(0, 0);
      lcd.print("NULLSTELLE");
      lcd.setCursor(0, 1);
      lcd.print("0.00ml - leer!");
      delay(1200);
      break;
    }

    // Stop Button gedrückt?
    if (digitalRead(BTN_START_STOP) == LOW) {
      motorStopped = true;
      operationDuration = (millis() - operationStartTime) / 1000;
      operationInProgress = false;
      totalSteps += i;
      motorRelease();
      delay(150);
      break;
    }

    // einen Schritt vorwärts (leeren)
    myStepper.step(1);
    noteActivity();

    if (i % 100 == 0) {
      float currentVol = abs((float)(totalSteps + i) / stepsPerML);
      unsigned long currentTime = (millis() - operationStartTime) / 1000;

      lcd.clear();
      lcd.setCursor(0, 0);
      lcd.print("Leeren:");
      lcd.print(currentVol, 2);
      lcd.print("ml");

      lcd.setCursor(0, 1);
      lcd.print(currentTime);
      lcd.print("s ");

      int currentHashes = (int)((currentVol / targetVolume) * 13.0);
      if (currentHashes > 13) currentHashes = 13;
      if (currentHashes < 0)  currentHashes = 0;
      for (int h = 0; h < currentHashes; h++) lcd.print("#");
    }
  }

  if (!motorStopped) {
    totalSteps += stepSize;
    operationDuration = (millis() - operationStartTime) / 1000;
    operationInProgress = false;
  }

  updatePumpDisplay();
  motorRelease();   // Motor freigeben nach Operation
  noteActivity();   // Timer zurücksetzen
  delay(80);
}

// ----------------- Display Anzeige updaten -----------------
void updatePumpDisplay() {
  lcd.clear();
  float currentVol = abs((float)totalSteps / stepsPerML);

  if (motorStopped) {
    lcd.setCursor(0, 0);
    lcd.print("V in der Spritze:");
    lcd.setCursor(0, 1);
    lcd.print(currentVol, 2);
    lcd.print("ml (5ml max)");
    return;
  }

  lcd.setCursor(0, 0);
  lcd.print("5ml Vol:");
  lcd.print(currentVol, 2);
  lcd.print("ml");

  lcd.setCursor(0, 1);
  if (motorRunning) {
    lcd.print("LAUFEND");
  } else {
    lcd.print("BEREIT");
  }
}

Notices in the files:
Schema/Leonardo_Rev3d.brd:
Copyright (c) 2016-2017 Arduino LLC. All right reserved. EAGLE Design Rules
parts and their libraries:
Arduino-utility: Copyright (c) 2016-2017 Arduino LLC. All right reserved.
